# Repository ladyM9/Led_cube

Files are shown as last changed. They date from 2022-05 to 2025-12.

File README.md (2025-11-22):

# Led_cube(8x8x8)
This project is based on the STM32F103C8T6 (Blue Pill) for controlling WS2812D (LED diodes). The LED cube is used for ambient lighting.
Various animations can be displayed on the LED cube, which makes it very impressive and interesting.

## ***How this project works***

The STM32F103C8T6 and WS2812D (LED diodes) cannot be directly connected because they operate at different voltage levels. 
To solve this issue, the LED diodes and STM32F103C8T6 are connected using a logic level converter. A computer power supply is used to power the LED cube.
It is necessary to use a computer power supply because when all 512 LEDs are lit, the LED cube requires a 20 A/5 V power source to function correctly.
Programming code upload on STM32F103C8T6 with ST-Link.

## ***Contents of repo***
- Programming code for controlling the LED cube
- 3D design of the stand for the Led cube
- PCB for the Led cube(It is currently being created)
- Images of the Led cube

## ***Commponets for project:***
- STM32F103C8T6
- ST-Link
- WS2812D(512 piece)
- Capacitors(100 nF)
- Power supply(20A/5V)
- Logic Level Converter
- Wires for BreadBoard
- 3D printer(optional)
- 3D printing filament

<p align="center">
  
 <br>
    <b>View of the Led cube and the 3d print stand</b>
</p>
<br>

<p align="center">
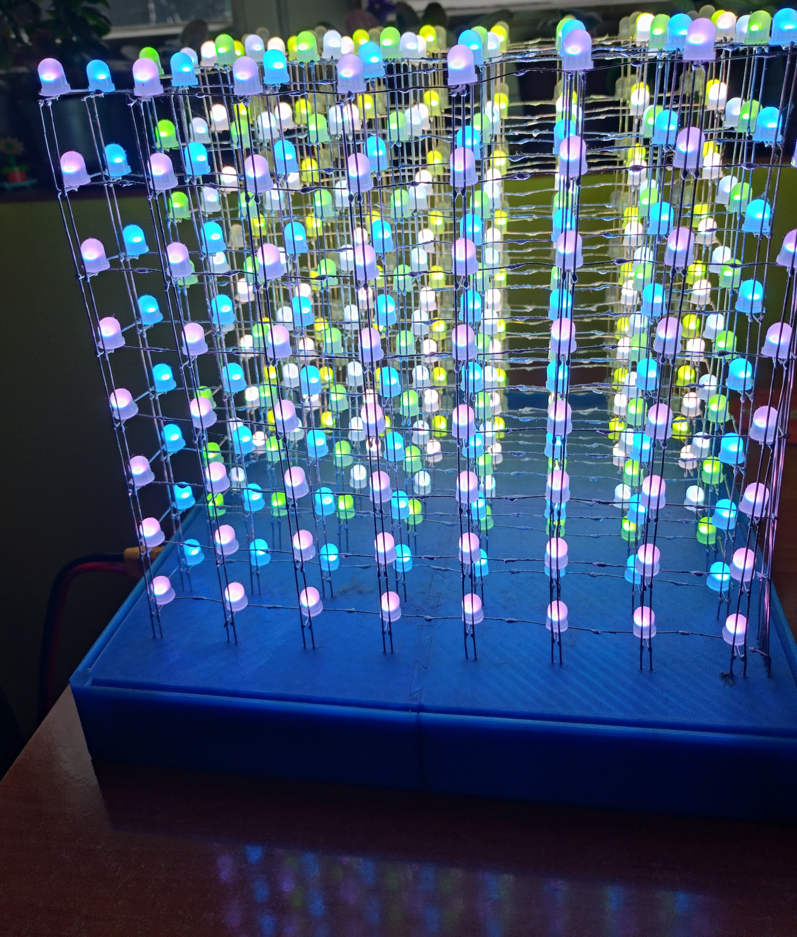
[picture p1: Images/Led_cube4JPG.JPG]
  
 <br>
    <b>Overview when all leds diodes working</b>
</p>
<br>

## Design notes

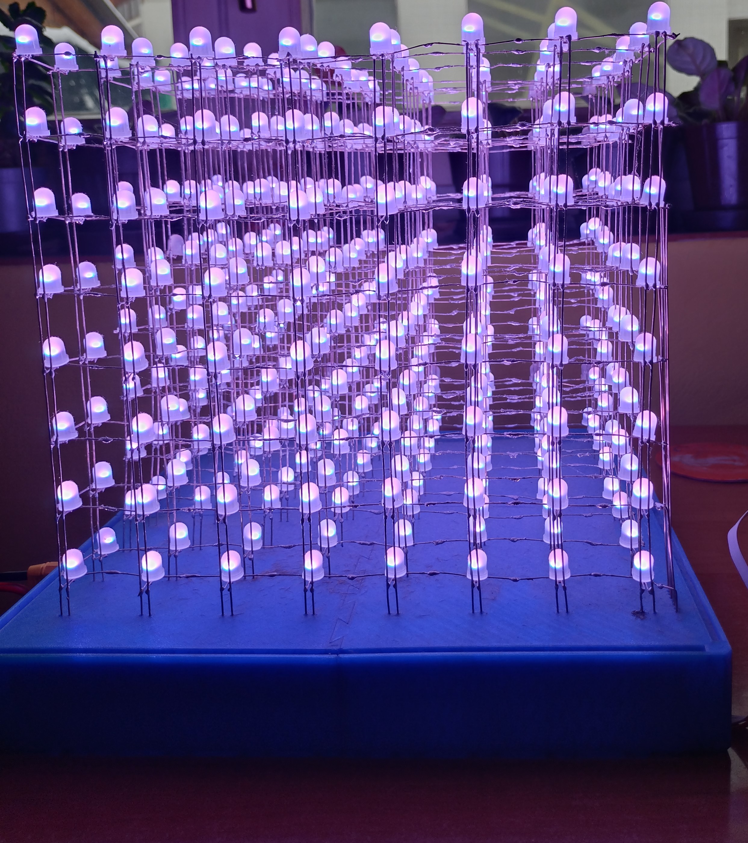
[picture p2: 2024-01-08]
Images/Led_cube3.JPG

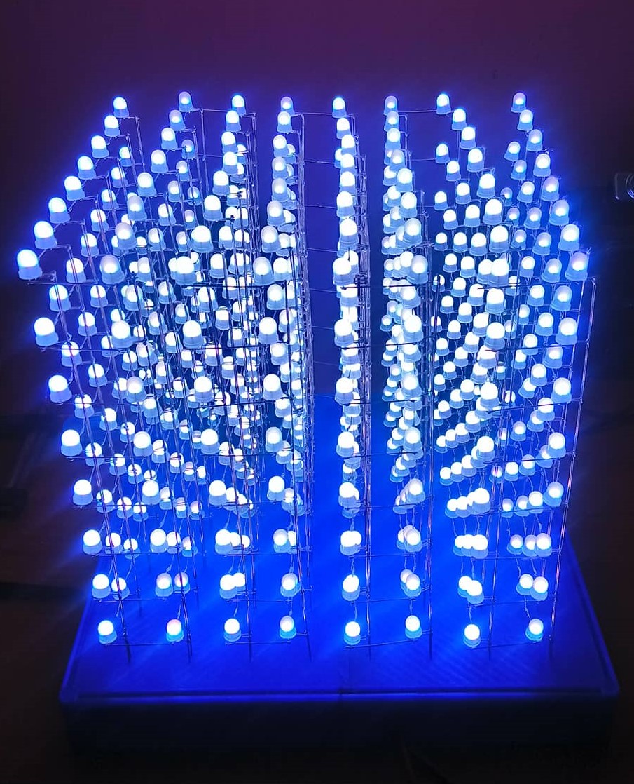
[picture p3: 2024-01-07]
Images/LED_CUBE.jpg

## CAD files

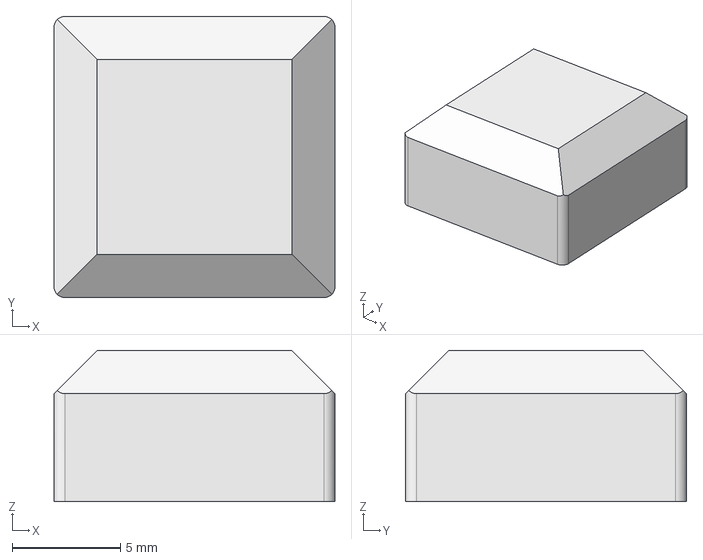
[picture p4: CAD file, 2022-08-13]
LED_CUBE_DESIGN/LED_Cube_Feets.FCStd
13.0 x 13.0 x 7.00 mm

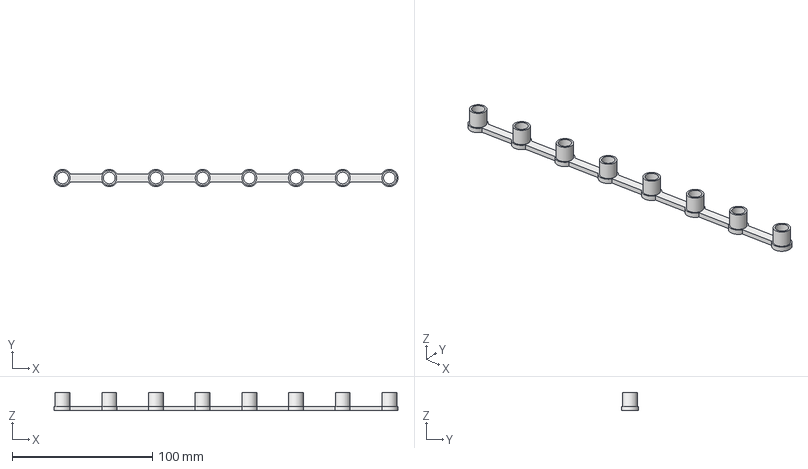
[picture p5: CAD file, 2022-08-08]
LED_CUBE_DESIGN/Holder za LEDice.FCStd
245.6 x 12.3 x 13.0 mm

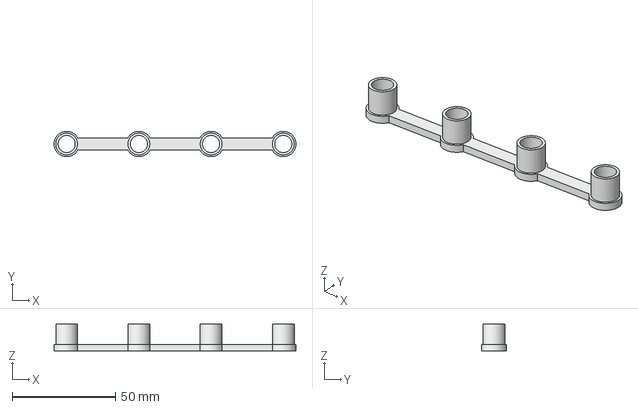
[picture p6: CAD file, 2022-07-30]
LED_CUBE_DESIGN/Tool za prepravak razmaka između ledica.FCStd
117.3 x 12.3 x 13.0 mm

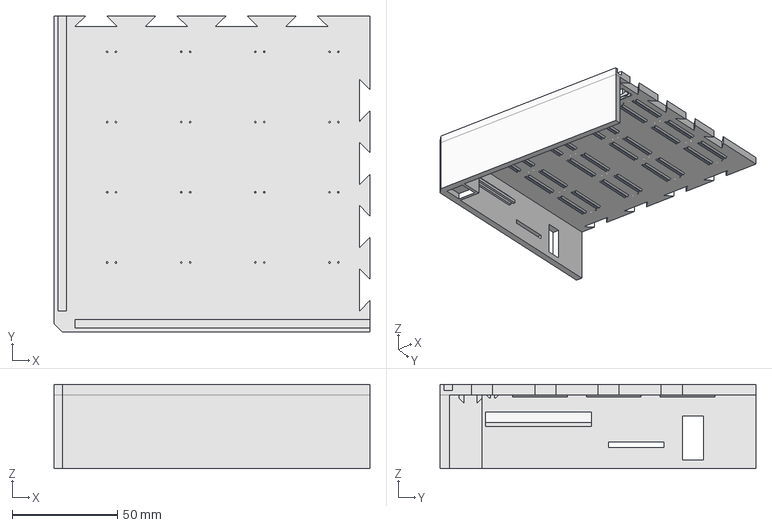
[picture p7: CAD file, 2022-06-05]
LED_CUBE_DESIGN/LED CUBE_LIJEVI DONJI DIO ISPRAVAK.FCStd
150.0 x 150.0 x 40.0 mm

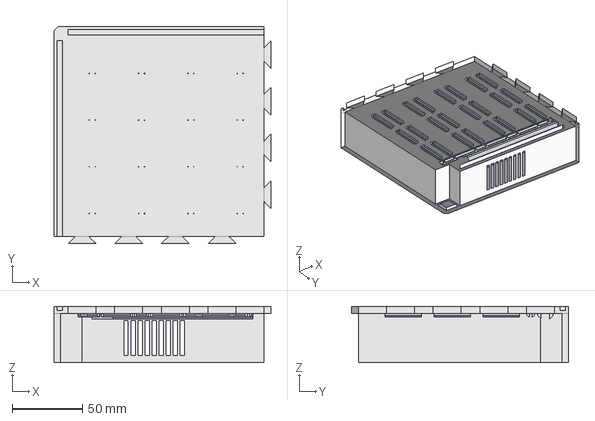
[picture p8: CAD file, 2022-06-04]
LED_CUBE_DESIGN/Lijevi gornji dio - NOVO ISPRAVNO.FCStd
154.9 x 154.9 x 40.0 mm

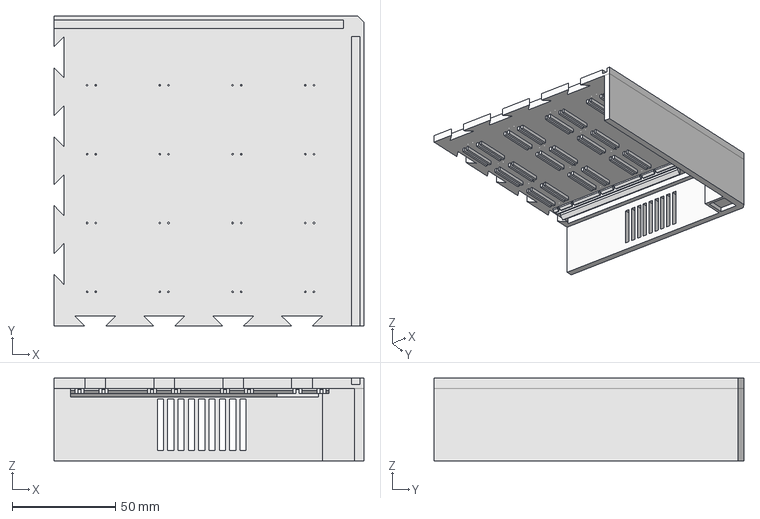
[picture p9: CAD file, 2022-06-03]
LED_CUBE_DESIGN/Desni_gornji_dio_Led_cube.FCStd
150.0 x 150.0 x 40.0 mm

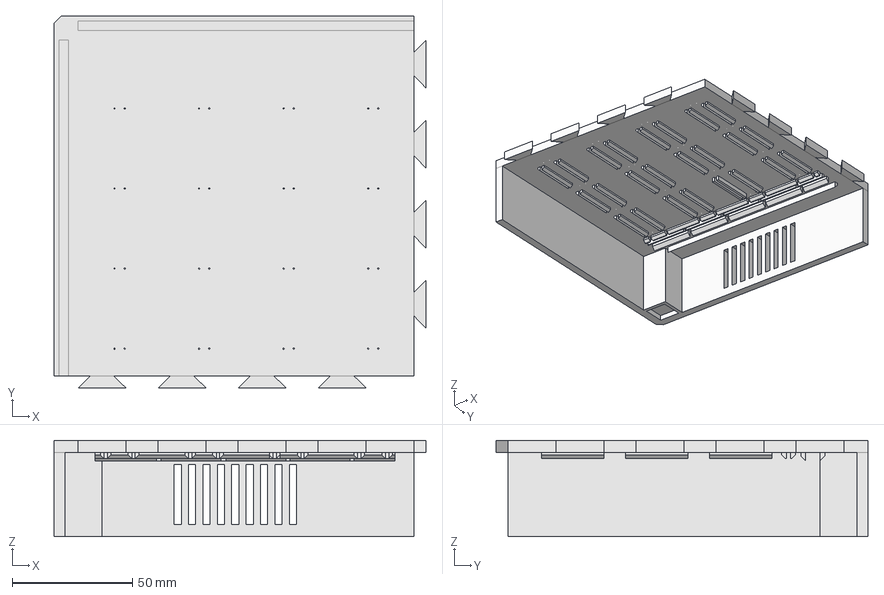
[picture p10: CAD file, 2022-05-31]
LED_CUBE_DESIGN/Lijevi gornji dio ispravak Led cube.FCStd
154.9 x 154.9 x 40.0 mm

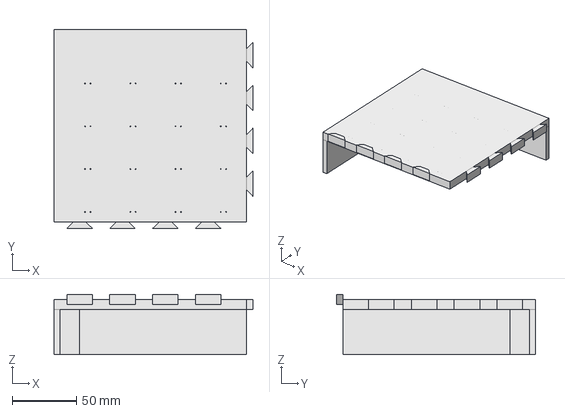
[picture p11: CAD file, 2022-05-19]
LED_CUBE_DESIGN/Lijevi gornji dio LED_CUBE.FCStd
154.9 x 154.9 x 47.0 mm

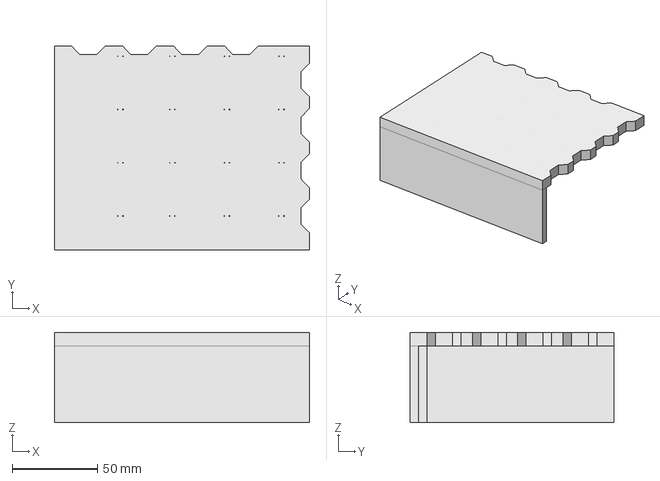
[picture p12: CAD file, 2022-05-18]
LED_CUBE_DESIGN/Lijevi donji dio_led cube.FCStd
150.0 x 120.0 x 53.0 mm

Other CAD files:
LED_CUBE_DESIGN/Desni donji dio led_cube.FCStd

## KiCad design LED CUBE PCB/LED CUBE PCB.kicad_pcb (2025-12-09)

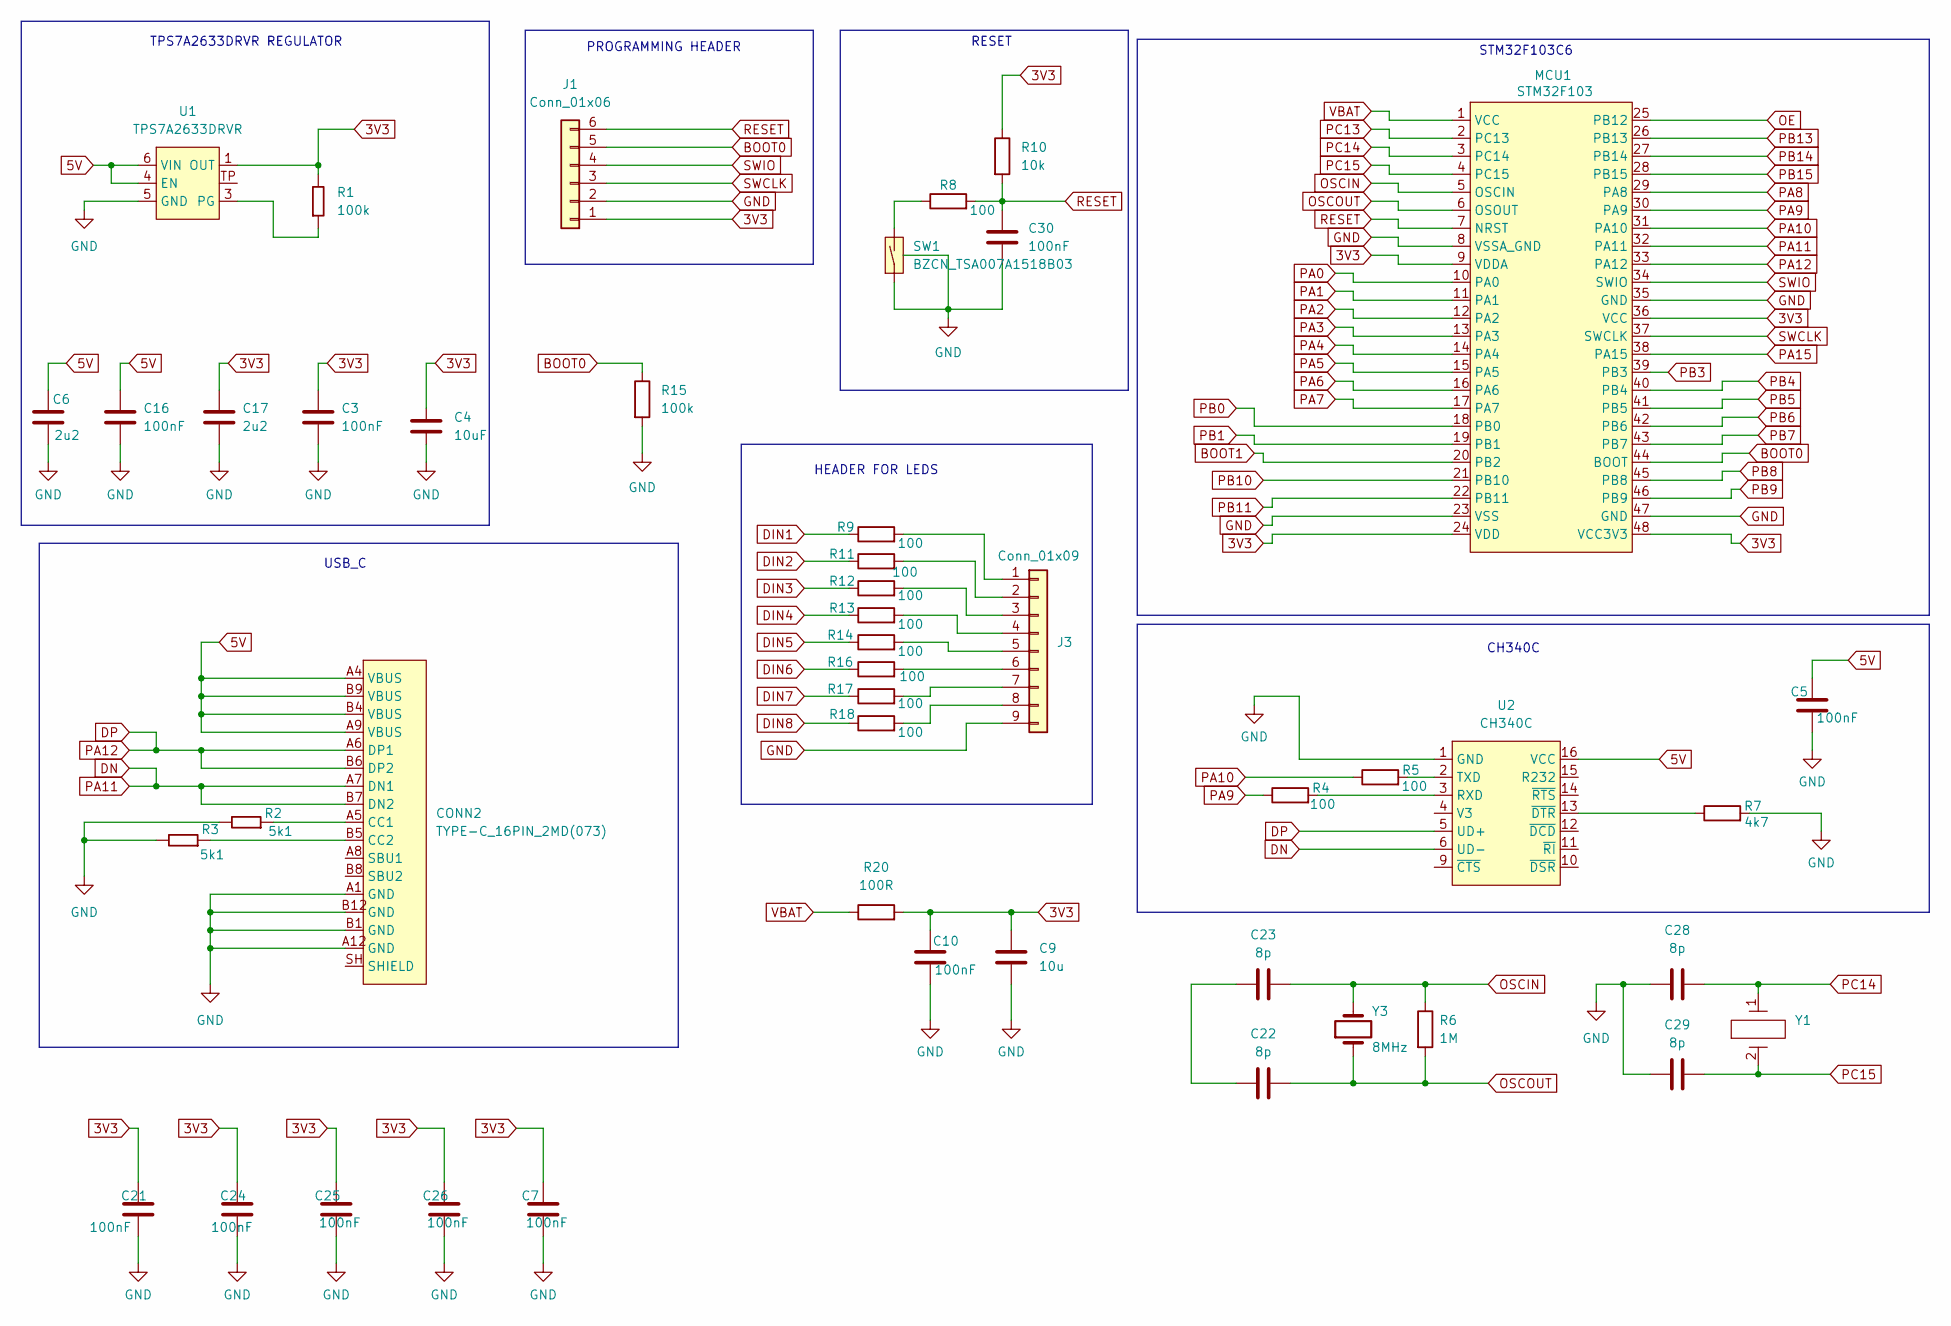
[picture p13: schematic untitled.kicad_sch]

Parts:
C3, C5, C7, C10, C16, C21, C24, C25, C26: 100nF; C0603
C4: 10uF; C1206
C6, C17: 2u2; C0603
C9: 10u; C1206
C22, C23, C28, C29: 8p; C0603
C30: 100nF; R0603
CONN2: TYPE-C_16PIN_2MD(073)
J1: Conn_01x06; PinHeader_1x06_P2.54mm_Vertical
J3: Conn_01x09; PinHeader_1x09_P2.54mm_Vertical
MCU1: STM32F103; TQFP48
R1, R15: 100k; R0603
R2, R3: 5k1; R0603
R4, R5, R8, R9, R11, R12, R13, R14, R16, R17, R18: 100; R0603
R6: 1M; R1206
R7: 4k7; R0603
R10: 10k; R0603
R20: 100R; R0603
SW1: BZCN_TSA007A1518B03; TSA007A1518B03
U1: TPS7A2633DRVR; WSON-6
U2: CH340C; SOP-16
Y1: SMD3215-2P
Y3: 8MHz; ECS-080-18-23G-JGN-TR

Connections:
3V3: C3.1, C4.2, C7.1, C9.2, C10.1, C17.1, C21.1, C24.1, C25.1, C26.1, J1.1, MCU1.9 (VDDA), MCU1.24 (VDD), MCU1.36 (VCC), MCU1.48 (VCC3V3), R1.2, R10.1, R20.2, U1.1 (OUT); also elsewhere on the board
5V: C5.1, C6.1, C16.1, CONN2.A4 (VBUS), CONN2.A9 (VBUS), CONN2.B4 (VBUS), CONN2.B9 (VBUS), U1.4 (EN), U1.6 (VIN), U2.16 (VCC); also elsewhere on the board
BOOT0: J1.5, MCU1.44 (BOOT), R15.1
BOOT1: MCU1.20 (PB2)
DIN1: R9.1; also elsewhere on the board
DIN2: R11.1; also elsewhere on the board
DIN3: R12.1; also elsewhere on the board
DIN4: R13.1; also elsewhere on the board
DIN5: R14.1; also elsewhere on the board
DIN6: R16.1; also elsewhere on the board
DIN7: R17.1; also elsewhere on the board
DIN8: R18.1; also elsewhere on the board
DN: CONN2.A7 (DN1), CONN2.B7 (DN2), MCU1.32 (PA11), U2.6 (UD-)
DP: CONN2.A6 (DP1), CONN2.B6 (DP2), MCU1.33 (PA12), U2.5 (UD+)
GND: C3.2, C4.1, C5.2, C6.2, C7.2, C9.1, C10.2, C16.2, C17.2, C21.2, C24.2, C25.2, C26.2, C28.1, C29.1, C30.2, CONN2.A1 (GND), CONN2.A12 (GND), CONN2.B1 (GND), CONN2.B12 (GND), J1.2, J3.9, MCU1.8 (VSSA_GND), MCU1.23 (VSS), MCU1.35 (GND), MCU1.47 (GND), R2.2, R3.2, R7.2, R15.2, SW1.1 (SW1), SW1.PAD, U1.5 (GND), U2.1 (GND); also elsewhere on the board
unnamed: C22.2, C23.2
unnamed: CONN2.A5 (CC1), R2.1
unnamed: CONN2.B5 (CC2), R3.1
unnamed: J3.1, R9.2
unnamed: J3.2, R11.2
unnamed: J3.3, R12.2
unnamed: J3.4, R13.2
unnamed: J3.5, R14.2
unnamed: J3.6, R16.2
unnamed: J3.7, R17.2
unnamed: J3.8, R18.2
unnamed: R8.1, SW1.2 (SW2)
unnamed: R1.1, U1.3 (PG)
unnamed: R4.2, U2.3 (RXD)
unnamed: R5.2, U2.2 (TXD)
unnamed: R7.1, U2.13 (~DTR)
OE: MCU1.25 (PB12); also elsewhere on the board
OSCIN: C23.1, MCU1.5 (OSCIN), R6.1, Y3.2
OSCOUT: C22.1, MCU1.6 (OSOUT), R6.2, Y3.1
PA0: MCU1.10 (PA0); also elsewhere on the board
PA1: MCU1.11 (PA1)
PA2: MCU1.12 (PA2)
PA3: MCU1.13 (PA3)
PA4: MCU1.14 (PA4)
PA5: MCU1.15 (PA5)
PA6: MCU1.16 (PA6)
PA7: MCU1.17 (PA7)
PA8: MCU1.29 (PA8)
PA9: MCU1.30 (PA9), R4.1
PA10: MCU1.31 (PA10), R5.1
PA15: MCU1.38 (PA15)
PB0: MCU1.18 (PB0); also elsewhere on the board
PB1: MCU1.19 (PB1)
PB3: MCU1.39 (PB3)
PB4: MCU1.40 (PB4); also elsewhere on the board
PB5: MCU1.41 (PB5); also elsewhere on the board
PB6: MCU1.42 (PB6); also elsewhere on the board
PB7: MCU1.43 (PB7); also elsewhere on the board
PB8: MCU1.45 (PB8); also elsewhere on the board
PB9: MCU1.46 (PB9); also elsewhere on the board
PB10: MCU1.21 (PB10)
PB11: MCU1.22 (PB11)
PB13: MCU1.26 (PB13)
PB14: MCU1.27 (PB14)
PB15: MCU1.28 (PB15)
PC13: MCU1.2 (PC13)
PC14: C28.2, MCU1.3 (PC14), Y1.1
PC15: C29.2, MCU1.4 (PC15), Y1.2
RESET: C30.1, J1.6, MCU1.7 (NRST), R8.2, R10.2
SWCLK: J1.3, MCU1.37 (SWCLK)
SWIO: J1.4, MCU1.34 (SWIO)
VBAT: MCU1.1 (VCC), R20.1

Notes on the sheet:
RESET
TPS7A2633DRVR REGULATOR
STM32F103C6
HEADER FOR LEDS
PROGRAMMING HEADER
USB_C
CH340C

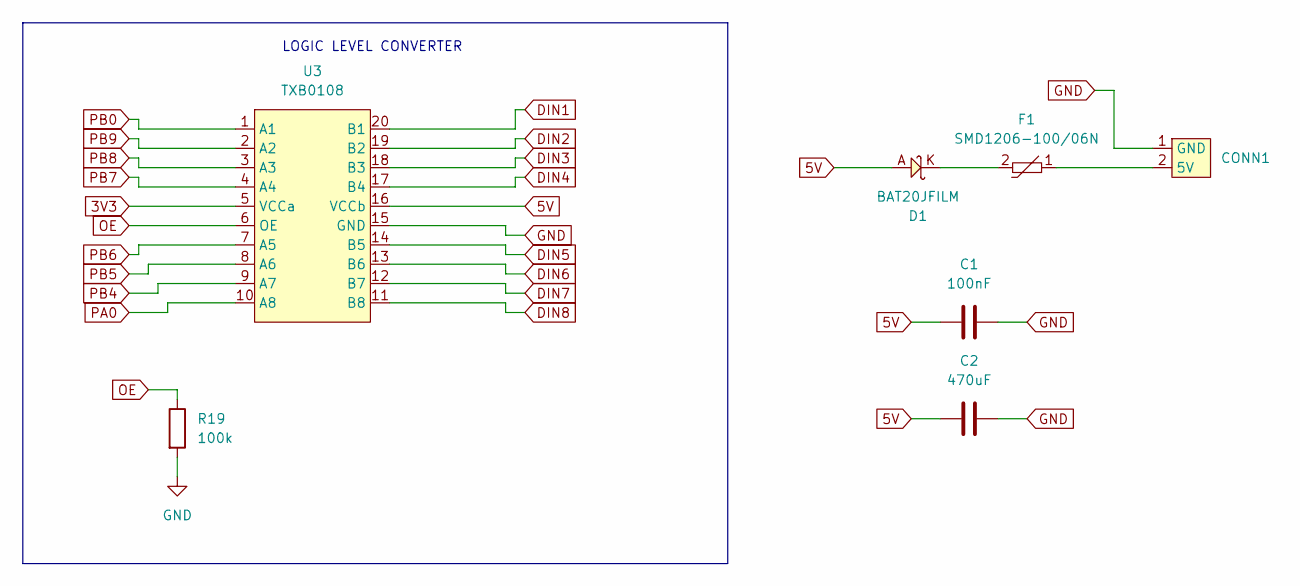
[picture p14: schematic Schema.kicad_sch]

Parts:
C1: 100nF; C0603
C2: 470uF; C0603
CONN1: POWER_SUPPLY; PinSocket_1x02_P2.54mm_Vertical
D1: BAT20JFILM; SOD323
F1: SMD1206-100/06N; 1206
R19: 100k; R0603
U3: TXB0108

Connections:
3V3: U3.5 (VCCa); also elsewhere on the board
5V: C1.2, C2.2, D1.A, U3.16 (VCCb); also elsewhere on the board
DIN1: U3.20 (B1); also elsewhere on the board
DIN2: U3.19 (B2); also elsewhere on the board
DIN3: U3.18 (B3); also elsewhere on the board
DIN4: U3.17 (B4); also elsewhere on the board
DIN5: U3.14 (B5); also elsewhere on the board
DIN6: U3.13 (B6); also elsewhere on the board
DIN7: U3.12 (B7); also elsewhere on the board
DIN8: U3.11 (B8); also elsewhere on the board
GND: C1.1, C2.1, CONN1.1 (GND), R19.2, U3.15 (GND); also elsewhere on the board
unnamed: CONN1.2 (5V), F1.1
unnamed: D1.K, F1.2
OE: R19.1, U3.6 (OE); also elsewhere on the board
PA0: U3.10 (A8); also elsewhere on the board
PB0: U3.1 (A1); also elsewhere on the board
PB4: U3.9 (A7); also elsewhere on the board
PB5: U3.8 (A6); also elsewhere on the board
PB6: U3.7 (A5); also elsewhere on the board
PB7: U3.4 (A4); also elsewhere on the board
PB8: U3.3 (A3); also elsewhere on the board
PB9: U3.2 (A2); also elsewhere on the board

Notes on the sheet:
LOGIC LEVEL CONVERTER

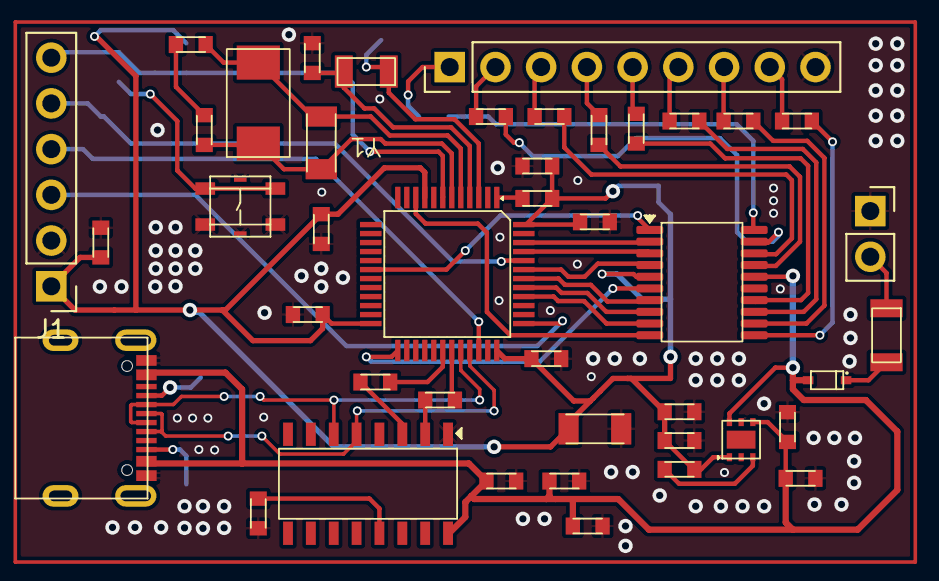
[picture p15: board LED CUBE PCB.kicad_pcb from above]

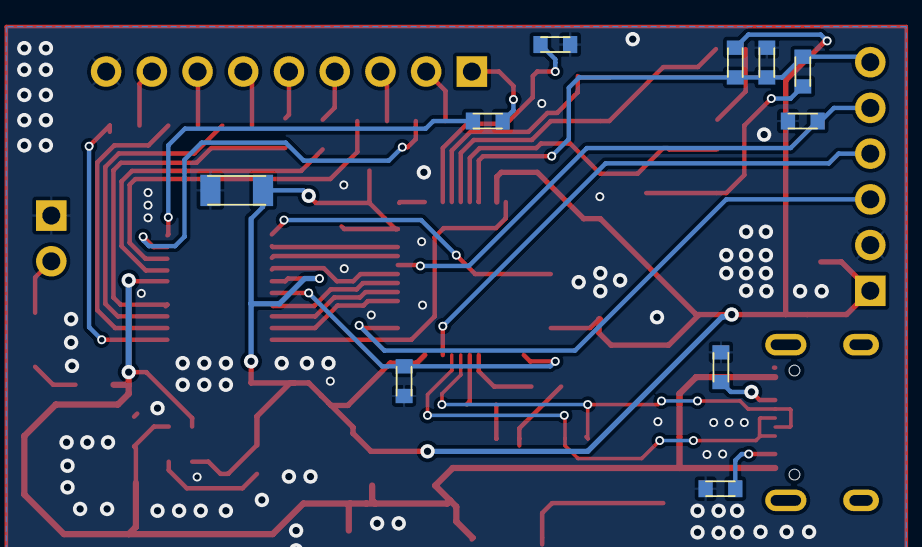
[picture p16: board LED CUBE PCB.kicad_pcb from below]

Board: 2 copper layers, 53 parts (10 on the bottom side), 51 nets.

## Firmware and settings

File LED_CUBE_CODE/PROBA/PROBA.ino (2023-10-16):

#include "GFX_LED_Cube.h"
//#include <Adafruit_GFX.h>
LEDCube myCube;
//void drawRect(uint16_t x0, uint16_t y0, uint16_t w, uint16_t h, uint16_t color);
uint16_t x0[] = {0, 1, 2, 3, 4, 5, 6};
uint16_t y[] = {0, 1, 2, 3, 4, 5, 6, 7, 8};
char slova[5] = {'F', 'E', 'R', 'I', 'T'};
char slova_2[8] = {'L', 'E', 'D', '_', 'C', 'U', 'B', 'E'};
uint16_t linijax[5] = {0,2,4,6,8};
uint16_t color[] = {12555, 123, 29857, 35214, 48975, 60000, 18000, 7841};
unsigned long previousMillis = 0;
const long interval = 1000;
const long interval2 = 10000;

unsigned long change_Timer = 0;
int pattern = 0;
unsigned long TIMER_CHANGE_INTERVAL = 5000;
void setup() {
  // put your setup code here, to run once:
  //  uint16_t x0 = 1;
  //  uint16_t x1 = 5;
  //  uint16_t y0 = 0;
  //  uint16_t y1 = 5;
  //  uint16_t color_1 = 32158;
  //  uint16_t w = 5 ;
  //  uint16_t h = 5 ;

  myCube.begin();
  // myCube.clear();
  // myCube.drawRect( 0, 2, 4, 4, 12555);
  //myCube.drawChar(0, 0, 89, 65535, 0, 1);
  // myCube.display();
}
int i = 0;
void loop() {
  upadate_Animacije(pattern);  //pozivanje funkcije pattern
  //unsigned long currentMillis = millis()
  if ((unsigned long)(millis() - change_Timer) >= TIMER_CHANGE_INTERVAL)  ///ako je  razlika vremena otkad je upaljen mikroupravljač i vremena promjene vremena veća od promjene intervala učini sljedeće
  {
    change_Timer = millis();  //varijabli za promjenu timera priduži millis odnosno milisekunde odnosno kreni brojati
    pattern++;  //pattern je ustvari _p iz funkcije za promjenu animacije, pomoću _p odnosno pattern odabire se case tj animacija
    if (pattern > 10)  //ako su animacije odnosno caseovi došli do kraja postavi pattern na 0 i kreni ispočetka
    {
      pattern = 0;
    }
  }



  return;
}

//  // put your main code here, to run repeatedly:
// // if (currentMillis + previousMillis  < millis()  || millis() < previousMillis) {
////    previousMillis = currentMillis;
//    // save the last time you blinked the LED
//    for (int i = 0; i < 6 ; i++) {
//      myCube.setDepth(i);
//      myCube.drawRect( x0[i], 2, 4, 4, color[i]);
//      //myCube.drawChar(0, 0, 89, 65535, 0, 1);
//      myCube.display();
//      delay(250);
//    }
//  }
//  if (currentMillis > 2000 && currentMillis < 5000 ) {
//  myCube.clear();
//    myCube.setDepth(2);
//    myCube.fillCircle(2, 3, 2, 25874);
//    delay(250);
//    myCube.setDepth(4);
//    myCube.fillCircle(5, 3, 2, 45213);
//    myCube.display();
//  }
//  if ((currentMillis > 6000) && (currentMillis < 10000)) {
//    myCube.clear();
//    myCube.setCursor(1, 0);
//    myCube.setDepth(i % 8);
//    myCube.print((i++) % 9, DEC);
//    myCube.display();
//    delay(250);
//  }
//  if ((currentMillis > 10000) && (currentMillis < 12000)) {
//    myCube.clear();
//    myCube.setDepth(2);
//    myCube.drawLine(1, 1, 6, 5, 55879);
//    myCube.setDepth(5);
//    myCube.drawLine(1, 7, 1, 1, 22145);
//    myCube.display();
//  }
//  if ((currentMillis > 12000) && (currentMillis < 15000)) {
//    myCube.clear();
//    for (int i = 0; i < 8 ; i++) {
//      myCube.setDepth(i);
//      myCube.drawPixel(x0[i], y[i], color[i]);
//      myCube.display();
//      delay(250);
//    }
//    for (int i = 0; i > 8 ; i++) {
//      myCube.setDepth(i - 1);
//      myCube.drawPixel(x0[i], y[i], color[i]);
//      myCube.display();
//
//    }




void  upadate_Animacije(int _p)   ///funkcija pomoću koje odabirem animaciju koju želim da mi se prikazuje na led kocki
{
  switch (_p)
  {
    case 0:  //ispisivanje teksta LED_CUBE
      myCube.clear();
      for (int i = 0 ; i < 8 ; i++)
      {
        myCube.setCursor(0, 0);
        myCube.setDepth(7);      //PODEŠAVANJE Z OSI
        myCube.setPlane(1);       //PODEŠAVANJE STRANICE NA KOJOJ ŽELIM DA MI SE NEŠTO ISPISUJE NA LED KOCKI
        myCube.setTextColor(65535, 0);
        myCube.setTextSize(1);
        myCube.print(slova_2[i]);
        myCube.display();
        delay(500);
      }
      break;

    case 1:  //iscrtavanje krugova

      myCube.clear();
      for (int i = 0 ; i < 7 ; i++)
      {
        myCube.setPlane(0);
        myCube.setDepth(0);
        myCube.drawCircle(x0[i] , 3, 1, 30000);
        //myCube.drawPixel_3(5, 0 , 1256);
        myCube.display();
        delay(500);
      }
      for (int i = 0 ; i < 7 ; i++)
      {
        myCube.setPlane(1);
        myCube.setDepth(7);
        myCube.drawCircle(x0[i] , 3, 1, 12589);
        //myCube.drawPixel_3(5, 0 , 1256);
        myCube.display();
        delay(500);
      }
      break;
    case 2:
      myCube.clear();
      for (int i = 8 ; i > 0 ; i--)
      {
        myCube.setPlane(0);
        myCube.setDepth(3);
        myCube.drawPixel(3, y[i] , color[i]);
        myCube.setDepth(6);
        myCube.drawPixel(5, y[i] + 1 , color[i]);
        myCube.setDepth(8);
        myCube.drawPixel(1, y[i] + 1 , color[i]);
        myCube.setDepth(2);
        myCube.drawPixel(6, y[i] , color[i]);
        myCube.setDepth(1);
        myCube.drawPixel(0, y[i] , color[i]);
        myCube.display();
        delay(200);
      }
      for (int i = 0 ; i < 8 ; i++)
      {
        myCube.setPlane(0);
        myCube.setDepth(4);
        myCube.drawPixel(0, y[i] , 22500);
        myCube.setDepth(0);
        myCube.drawPixel(8, y[i]  , 41000);
        myCube.setDepth(7);
        myCube.drawPixel(5, y[i]  , 5289);
        myCube.display();
        delay(200);
      }
      break;

    case 3:
      myCube.clear();
      myCube.setPlane(0);
      for (int y = 8 ; y > 0 ; y--)
      {

        myCube.setDepth(3);
        myCube.drawCircle( 2, y, 1, 12458);
        delay(250);
        myCube.display();
      }
      for (int y = 0 ; y < 8 ; y++)
      {
        myCube.setDepth(1);
        myCube.drawCircle( 5, y, 1, 42158);
        delay(250);
        myCube.display();
      }
      for (int y = 0 ; y < 8 ; y++)
      {
        myCube.setDepth(7);
        myCube.drawCircle( 3, y, 1, 20000);
        delay(250);
        myCube.display();
      }
      break;
    case 4:
      myCube.clear();
      for (int i = 0; i < 6 ; i++)
      {
        myCube.setDepth(i);
        myCube.drawRect( x0[i], 2, 4, 4, color[i]);
        //myCube.drawChar(0, 0, 89, 65535, 0, 1);
        myCube.display();
        delay(250);
      } break;
    case 5:
      myCube.clear();
      for (int i = 0 ; i < 5; i++)
      {
        myCube.setCursor(0, 0);
        myCube.setDepth(0);
        myCube.setTextColor(65535, 0);
        myCube.setTextSize(1);
        myCube.print(slova[i]);
        myCube.display();
        delay(250);
      } break;
    case 6:
      myCube.clear();
      myCube.setCursor(1, 0);
      myCube.setDepth(i % 8);
      myCube.print((i++) % 9, DEC);
      myCube.display();
      delay(250);
      break;

    case 7:
      myCube.clear();
      for (int i = 0; i < 8 ; i++)
      {
        myCube.setDepth(i);
        myCube.drawPixel(x0[i], y[i], color[i]);
        myCube.display();
        delay(250);
      }
      for (int i = 8; i > 0 ; i--)
      {
        myCube.setDepth(8);
        myCube.drawPixel(x0[i], y[i], color[i]);
        myCube.display();
        delay(250);
      }
      for (int i = 0; i < 8 ; i++)
      {
        myCube.setDepth(i);
        myCube.drawPixel(x0[i], 0, color[i]);
        myCube.display();
        delay(250);
      } break;
    case 8:
      myCube.clear();
      for (int i = 0; i < 7 ; i++)
      {
        myCube.setDepth(i);
        myCube.drawFastVLine(x0[i], y[i], 4, 4587);
        myCube.display();
        delay(250);

      } break;
    case 9:
      myCube.clear();
      for (int i = 0 ; i < 7 ; i++)
      {
        myCube.setDepth(i);
        myCube.fillScreen(12589);
        myCube.display();
        delay(250);

      } break;
    case 10:
      myCube.clear();
      for(int i = 0 ; i < 7 ; i++)
      { 
      myCube.setDepth(i);
      myCube.drawFastVLine(linijax[i], 0, 8, color[i]);
      myCube.display();
      delay(250);
      }
      break;
  }
}

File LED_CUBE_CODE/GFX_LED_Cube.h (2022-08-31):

#ifndef __ADAFRUIT_GFX_CUBE_H__
#define __ADAFRUIT_GFX_CUBE_H__

#if ARDUINO >= 100
 #include "Arduino.h"
#else
 #include "WProgram.h"
#endif

#include <Adafruit_NeoPixel.h>
#include <Adafruit_GFX.h>

#define PIN1        PB0 // Connected to D2
#define PIN2        PB9 // Connected to D3
#define PIN3        PB8 // Connected to D4
#define PIN4        PB7 // Connected to D5
#define PIN5        PB6 // Connected to D6
#define PIN6        PB5 // Connected to D7
#define PIN7        PB4 // Connected to D8
#define PIN8        PA0 // Connected to D9
#define NUMPIXELS 	64 // How many LEDs there are on one layer
#define LAYERS		8

class LEDCube : public Adafruit_GFX {
	public:
	LEDCube();

  	void begin(void);
  	void clear(void);
  	void display(void);
  	void drawPixel(int16_t x, int16_t y, uint16_t color);
	void drawPixel_2(int16_t a, int16_t b, uint16_t color);
	void drawPixel_3(int16_t x1, int16_t y1, uint16_t color);
	void setDepth(int _d);
	void setDepth_2(int _d2);
	void setDepth_3(int _d3);

	private:
	Adafruit_NeoPixel *pixels[8];
	int _depth = 0;
	int _depth2 = 8;
	int _depth3 = 0;

};

#endif

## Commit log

2022-05-11 Create My models in Free Cad
2022-05-11 Create My Free CAD models
2022-05-29 Cooling mesh fixed on Desni donji dio led_cube.FCStd
    [Desni donji dio led_cube.FCStd]
2022-06-03 Nije chamfer napravljen do kraja, fale utori za pleksiglas, i nedostaje utor na donjoj strani
    [Lijevi gornji dio - NOVO ISPRAVNO.FCStd]
2022-06-04 Lijevi donji dio pregledat utore za konektore
    [LED CUBE_LIJEVI DONJI DIO ISPRAVAK.FCStd, Lijevi gornji dio - NOVO ISPRAVNO.FCStd]
2022-06-05 STM32 holder change, header and XT90 connector hole size change
    [LED CUBE_LIJEVI DONJI DIO ISPRAVAK.FCStd]
2022-07-26 Tool za prepravak razmaka, prva verzija
    [Tool za prepravak razmaka između ledica.FCStd]
2022-07-27 Verzija 2
    [Tool za prepravak razmaka između ledica.FCStd]
2022-07-28 Changed hole size for LED Tool.
    [Tool za prepravak razmaka između ledica.FCStd]
2022-07-30 Added cylinder around LED (for easier soldering).
    [Tool za prepravak razmaka između ledica.FCStd]
2022-08-06 Added holder for 8 LEDs (tool for 8 LEDs)
    [Holder za LEDice.FCStd]
2022-08-08 Changed distance between LEDs (from 35mm to 33.33mm)
    [Holder za LEDice.FCStd]
2022-08-13 Added 3D printed feets
    NOTE: Use TPU material, no retraction fore feets.
    [LED_Cube_Feets.FCStd]
2022-08-17 Prvi kod za led cube, neopixel example ustvari
2022-08-18 Uspješno prvo nijansiranje boja ali samo na prvom layeru, odnosno na 64 ledice, nijansirana je plava boja
2022-08-19 Upgrade nijansiranja, sada se boje mijenjaju kroz cijeli prvi layer, ledice periodički mijenjaju boju
2022-08-24 Prikaz 9 slova na led cube-u, dodan library koji povezuje NeoPixel i NeoMatrix
2022-08-26 Dodano više različitih oblika koje se prikazuju pojedinačno na led kocki
2022-08-29 Optimizacija timera, animacije se stalno mijenjaju na led kocki zbog pravilnog korištenja timera i intervala
2022-08-31 Ispisivanje moguće na dvije plohe led kocke, dodane još dvije animacije
2023-10-16 Files distributed in folders
    [Desni donji dio led_cube.FCStd, Desni_gornji_dio_Led_cube.FCStd, Holder za LEDice.FCStd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]
2024-01-08 Added pictures of led_cube
2024-01-16 PCB for LED_CUBE
    [LED CUBE PCB.kicad_pcb, LED CUBE PCB.kicad_sch, STM32F103.kicad_pcb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]
2024-01-19 Added shema and footprints
    [LED CUBE PCB.kicad_pcb, LED CUBE PCB.kicad_sch, LED_CUBE.kicad_sch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]
2024-01-24 Added header and global labels
    [LED_CUBE.kicad_sch, untitled.kicad_sch]
2024-05-14 Added logic level converter
    [LED CUBE PCB.kicad_sch, LED_CUBE.kicad_sch, Schema.kicad_sch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]
2024-10-02 Push changes
    [Schema.kicad_sch, untitled.kicad_sch]
2024-10-02 Deleted two CAD files
    [Proba za led cube.FCStd]
2025-11-18 Fixed problems on schematic
    [LED CUBE PCB.kicad_sch, Schema.kicad_sch, untitled.kicad_sch]
2025-11-18 Update schema
    [untitled.kicad_sch]
2025-11-19 Update PCB
2025-11-19 Added filtering for power supply
    [Schema.kicad_sch]
2025-11-19 Change voltage regulator
    [untitled.kicad_sch]
2025-11-20 Connected voltage regulator and logic level converter
    [Schema.kicad_sch, untitled.kicad_sch]
2025-11-21 Added USB C and CH340C
    [Schema.kicad_sch, untitled.kicad_sch]
2025-11-22 Corrected schema after review by Borna (Marina)
    [Schema.kicad_sch, untitled.kicad_sch]
2025-11-23 Replaced symbol for TXB and STM
    [Schema.kicad_sch, untitled.kicad_sch]
2025-11-24 Added fuse and bat20
    [Schema.kicad_sch, untitled.kicad_sch]
2025-11-25 Corrected RC filter(Marina)
    [untitled.kicad_sch]
2025-11-25 Schema is finished
    [LED CUBE PCB.kicad_pcb, Schema.kicad_sch, untitled.kicad_sch]
2025-11-26 Beginning PCB layout
    [LED CUBE PCB.kicad_pcb, untitled.kicad_sch]
2025-11-28 Updated routing PCB
    [LED CUBE PCB.kicad_pcb]
2025-11-30 Change footprint for capacitors and routing PCB
    [LED CUBE PCB.kicad_pcb, untitled.kicad_sch]
2025-12-01 Change footprint for crystal
    [LED CUBE PCB.kicad_pcb, untitled.kicad_sch]
2025-12-02 Updated PCB
    [LED CUBE PCB.kicad_pcb, untitled.kicad_sch]
2025-12-04 Added ground filled zone on PCB
    [LED CUBE PCB.kicad_pcb, untitled.kicad_sch]
2025-12-06 Problem with GND
    [LED CUBE PCB.kicad_pcb]
2025-12-06 Updated PCB - Marina
    [LED CUBE PCB.kicad_pcb, untitled.kicad_sch]
2025-12-07 PCB is finish
    [LED CUBE PCB.kicad_pcb, Schema.kicad_sch, untitled.kicad_sch]
2025-12-07 PCB is finished
2025-12-09 Solved problem with VCC3V3 and 3V3 on schematic
    [LED CUBE PCB.kicad_pcb, Schema.kicad_sch, untitled.kicad_sch]
